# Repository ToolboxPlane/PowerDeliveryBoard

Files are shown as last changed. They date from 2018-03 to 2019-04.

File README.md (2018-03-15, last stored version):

View this project on [CADLAB.io](https://cadlab.io/node/755). 

# PowerDeliveryBoard

This board provides and monitors a 5V and 3.3V rail and monitors battery voltage and current.

Top Side|Bottom Side
:-------------------------:|:-------------------------:
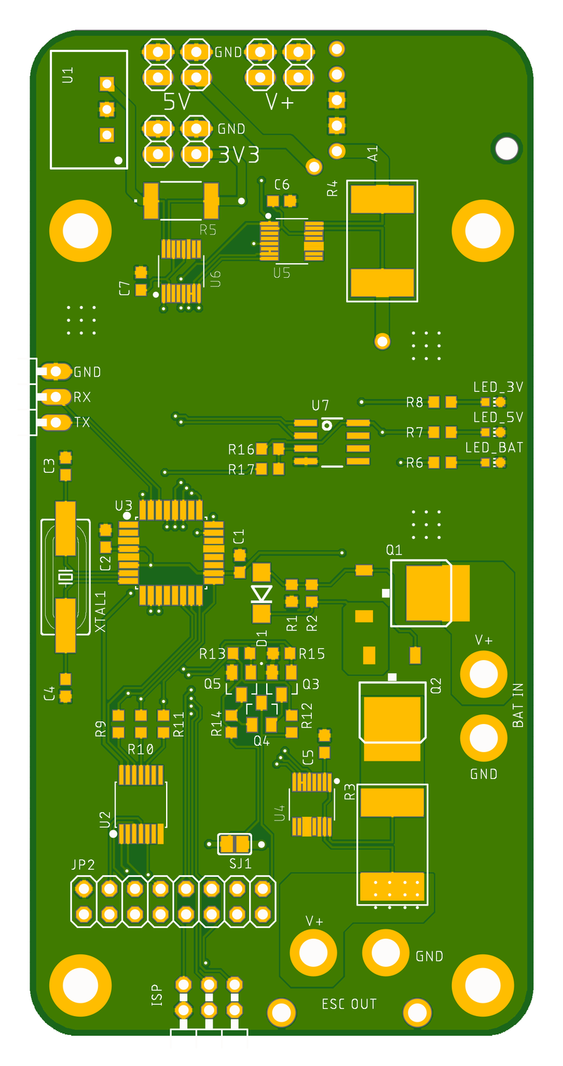
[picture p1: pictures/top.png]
Top Side
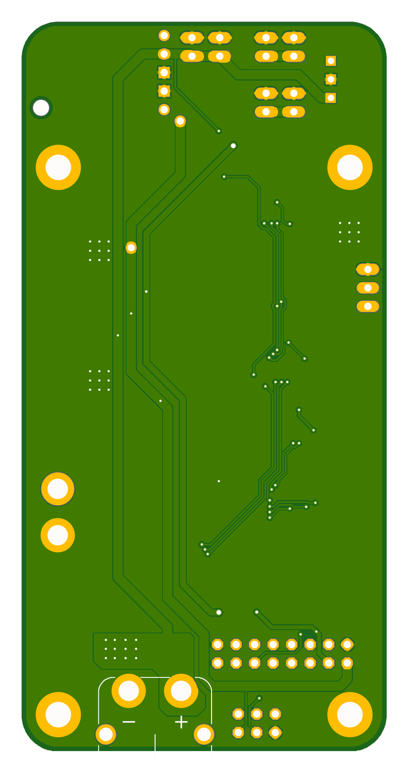
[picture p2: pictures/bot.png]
Bottom Side
|

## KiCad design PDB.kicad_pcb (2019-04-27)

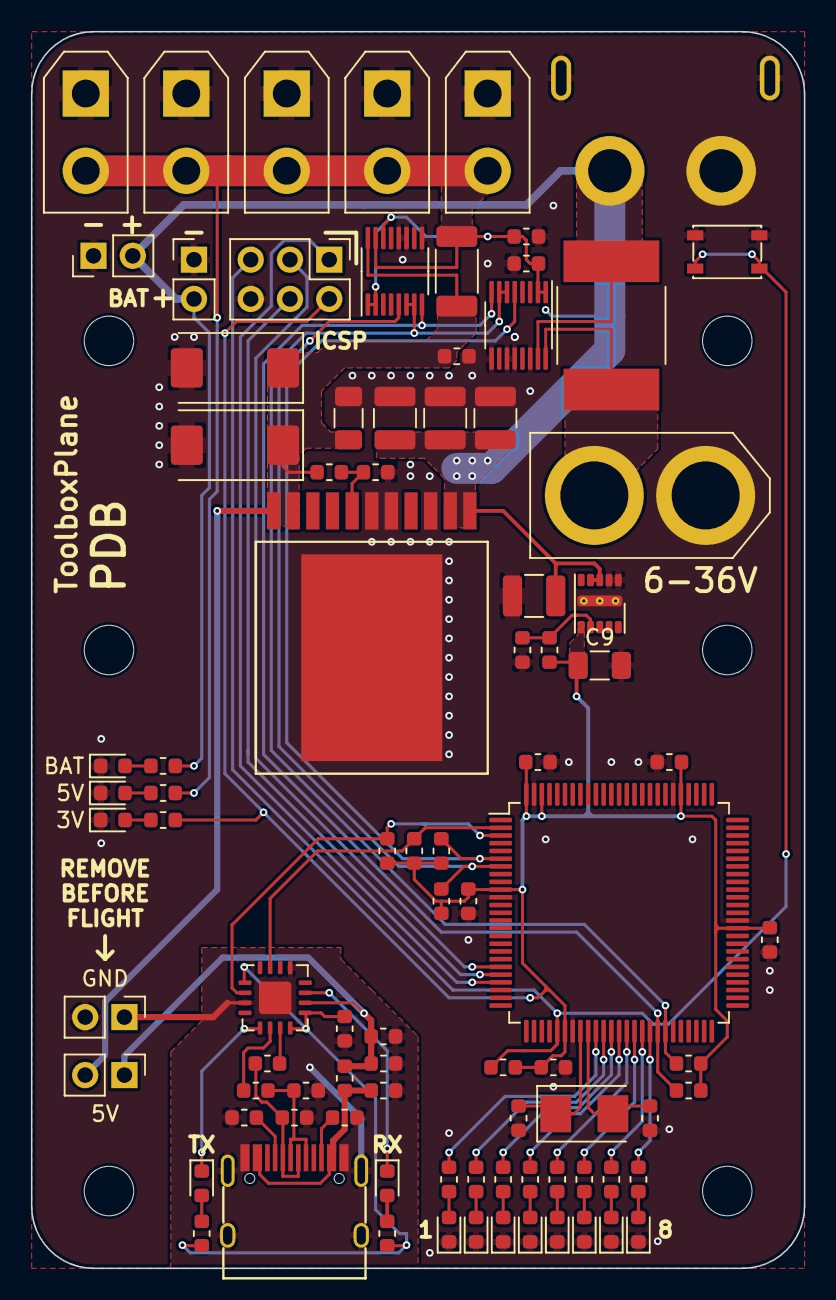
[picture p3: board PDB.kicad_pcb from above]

Board: 2 copper layers, 50.0 x 80.0 mm, 95 parts (0 on the bottom side), 53 nets.

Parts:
C1, C2: 8pF; C_0603_1608Metric
C3, C4, C5, C6, C7, C14, C16: 100nF; C_0603_1608Metric
C8: 10µF; C_1210_3225Metric
C9: 22µF; C_1206_3216Metric
C10, C24: 100n; C_0603_1608Metric
C11, C12: 47p; C_0603_1608Metric
C13: 10nF; C_0603_1608Metric
C15: 4.7µF; C_0603_1608Metric
C17, C18, C19: 10µ; C_1210_3225Metric
C20: 47n; C_0603_1608Metric
C21, C22: 330µ; CP_EIA-7343-31_Kemet-D
C23: 47µ; C_1206_3216Metric
D1: blue; LED_0603_1608Metric
D2: green; LED_0603_1608Metric
D3: orange; LED_0603_1608Metric
D4, D5, D6, D7, D8, D9, D10, D11: LED_0603_1608Metric
D12, D13: LED_Small; LED_0603_1608Metric
FB1: 600 Ohms @ 100MHz; C_0603_1608Metric
H1, H2, H3, H4, H5, H6: MountingHole; MountingHole_3.2mm_M3
J1, J2, J3, J4, J5: Conn_01x02; AMASS_XT30UPB-F_1x02_P5.0mm_Vertical
J6, J7: Conn_01x02; PinHeader_1x02_P2.54mm_Vertical
J8: Conn_01x02; XT60PB-M
J9: Conn_02x03_Odd_Even; PinHeader_2x03_P2.54mm_Vertical
J10: Conn_01x02_MountingPin; XT60PW-F
J11: USB_C_Receptacle_USB2.0; USB_C_Receptacle_GT-USB-7010
JP1, JP2: Jumper; PinHeader_1x02_P2.54mm_Vertical
R1, R29: 2.8k; R_0603_1608Metric
R2, R3, R14, R15, R16, R17, R18: 10k; R_0603_1608Metric
R4: 470; R_0603_1608Metric
R5, R26, R27: 270; R_0603_1608Metric
R6, R7, R8, R9, R10, R11, R12, R13: 100; R_0603_1608Metric
R19: 11.5k; R_0603_1608Metric
R20: 4.99k; R_0603_1608Metric
R21: 2m; R_3920
R22, R23: 5.1k; R_0603_1608Metric
R24, R25: 27; R_0603_1608Metric
R28: 14.7k; R_0603_1608Metric
R30: 8m; R_2010_5025Metric
SW1: SW_Push; SW_SPST_PTS810
U1: ATmega2560-16AU; TQFP-100_14x14mm_P0.5mm
U2: LMZM23600; Texas_SIL0010A_MicroSiP-10-1EP_3.8x3mm_P0.6mm_EP0.7x2.9mm_T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
U3, U6: LTC2946; MSOP-16_3x4mm_P0.5mm
U4: FT230XQ; QFN-16-1EP_4x4mm_P0.65mm_EP2.1x2.1mm
U5: LMZ13608
Y1: 16MHz; Crystal_SMD_5032-2Pin_5.0x3.2mm

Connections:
+3V3: C3.2, C4.2, C5.2, C6.2, C7.2, C9.1, J9.2, R2.1, R3.1, R5.1, R14.1, R15.1, R16.1, R17.1, R18.1, R19.1, U1.10, U1.31, U1.61, U1.80, U1.98, U1.100, U2.6
+5V: C10.1, C24.1, J1.2, J2.2, J3.2, J4.2, J5.2, R4.1, R30.1, U3.1, U3.2, U6.1, U6.2, U6.14, U6.15
+BATT: C8.1, C17.1, C18.1, C19.1, J6.2, J7.2, J10.2, R1.1, R21.1, U2.3, U2.4, U3.15, U5.1, U5.2
/5V/5VIN: C20.1, C21.1, C22.1, C23.1, JP1.2, R28.1, R30.2, U5.10, U5.11, U6.16
/ATMega/MISO: J9.1, U1.22
/ATMega/MOSI: J9.4, U1.21
/ATMega/SCK: J9.3, U1.20
/ATMega/~RESET~: J9.5, R14.2, SW1.2, U1.30
/BAT/VBATIN: J8.2, R21.2, U3.16
/FT230/5VOUT: C14.1, C15.1, FB1.1, JP1.1, U4.10
/RX: R2.2, U1.2, U4.15
/SCL: R16.2, U1.43, U3.8, U6.8
/SDA: R15.2, U1.44, U3.6, U3.7, U6.6, U6.7
/TX: R3.2, U1.3, U4.2
/~ALERT_+5V~: R18.2, U1.7, U6.5
/~ALERT_VBAT~: R17.2, U1.6, U3.5
GND: C1.2, C2.2, C3.1, C4.1, C5.1, C6.1, C7.1, C8.2, C9.2, C10.2, C17.2, C18.2, C19.2, C20.2, C21.2, C22.2, C23.2, C24.2, D1.1, D2.1, D3.1, D4.1, D5.1, D6.1, D7.1, D8.1, D9.1, D10.1, D11.1, J1.1, J2.1, J3.1, J4.1, J5.1, J6.1, J7.1, J8.1, J9.6, J10.1, J10.MP, JP2.2, R20.1, R29.2, SW1.1, U1.11, U1.32, U1.62, U1.81, U1.99, U2.1, U2.2, U2.11, U3.9, U3.11, U3.12, U3.14, U5.3, U5.5, U5.6, U5.PAD, U6.9, U6.11, U6.12
GNDS: C11.2, C12.2, C13.2, C14.2, C15.2, C16.2, J11.A1, J11.A12, J11.B1, J11.B12, J11.S1, JP2.1, R22.1, R23.1, U4.3, U4.13, U4.17
unnamed: C1.1, U1.34, Y1.2
unnamed: C2.1, U1.33, Y1.1
unnamed: C11.1, J11.A7, J11.B7, R24.2
unnamed: C12.1, J11.A6, J11.B6, R25.2
unnamed: C16.1, R26.1, R27.1, U4.1, U4.8, U4.9
unnamed: D1.2, R1.2
unnamed: D2.2, R4.2
unnamed: D3.2, R5.2
unnamed: D4.2, R6.2
unnamed: D5.2, R7.2
unnamed: D6.2, R8.2
unnamed: D7.2, R9.2
unnamed: D8.2, R10.2
unnamed: D9.2, R11.2
unnamed: D10.2, R12.2
unnamed: D11.2, R13.2
unnamed: D12.1, U4.11
unnamed: D12.2, R26.2
unnamed: D13.1, U4.5
unnamed: D13.2, R27.2
unnamed: J11.A5, R22.2
unnamed: J11.B5, R23.2
unnamed: R6.1, U1.35
unnamed: R7.1, U1.36
unnamed: R8.1, U1.37
unnamed: R9.1, U1.38
unnamed: R10.1, U1.39
unnamed: R11.1, U1.40
unnamed: R12.1, U1.41
unnamed: R13.1, U1.42
unnamed: R19.2, R20.2, U2.7
unnamed: R24.1, U4.7
unnamed: R25.1, U4.6
unnamed: R28.2, R29.1, U5.7
VBUS: C13.1, FB1.2, J11.A4, J11.A9, J11.B4, J11.B9

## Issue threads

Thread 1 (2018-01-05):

Platzierung der hohen Bauteile

niklas26, 2018-01-05:
Optionen:
-Längeres Board
-höhere Pinnleisten
-?

aul12, 2018-01-05:
Bin für längeres Board. Dann können in der überstehenden Fläche zusätzliche Schraublöcher angebracht werden und der komplette Stack einfach daran festgeschraubt werden und die Platinen müssen nicht nacheinander festgeschraubt werden

Closed 2018-01-25.

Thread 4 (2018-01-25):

Welchen Sinn hat L2 hinter dem Traco?

swappad, 2018-01-25:
Nicht lieber davor?

niklas26, 2018-01-30:
Ne das passt schon so, wird geglättet wenn das Signal raus kommt.
Siehe dazu auch das DB des Tracos

Closed 2018-03-12.

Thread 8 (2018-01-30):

Select appropriate shunt for 3v3, 5v

ottojo, 2018-01-30:

ottojo, 2018-01-30:
Done: 5V uses the same 2mOhm as VBAT,
3V3 uses "CRA2512-FZ-R040ELF" 40mOhm in 2512 package

This results in a resoultion of:

Voltage | Maximum Current | Resolution
-- | -- | --
VBAT (<= 16.8V) | 51,2A | 12.5mA
5V | 51,2A | 12.5mA
3V3 | 2,56A | 0,625mA

Closed 2018-02-01.

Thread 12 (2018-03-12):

fix atmega footprint

ottojo, 2018-03-12:
footprint does not match TQFP package

Closed 2018-03-12.

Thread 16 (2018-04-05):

Add Power Monitoring to new board

ottojo, 2018-04-05:
Well maybe we remember to connect the enable pin now, on the second try...
OE should be connected to 3V3

Closed 2018-08-22.

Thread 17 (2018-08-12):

Implement 5V regulation

ottojo, 2018-08-12:
U_BAT (12V-17V) to 5V, ~5A (?)

ottojo, 2018-08-12:
Suggestion: Texas Instruments LMZ12008TZ ([digikey](https://www.digikey.de/product-detail/de/texas-instruments/LMZ12008TZ-NOPB/LMZ12008TZ-NOPB-ND/2626433))

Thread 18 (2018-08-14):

USB to UART for communication with FlightComputer

ottojo, 2018-08-14:

ottojo, 2018-08-14:
FT230XQ

ottojo, 2018-08-22:
TODO: figure out if pull-up resistors are needed on rx/tx

ottojo, 2018-08-22:
todo: see above

ottojo, 2019-03-12:
https://github.com/ToolboxPlane/FT230Module

Closed 2019-03-12.

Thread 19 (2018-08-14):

Figure out naming (Delivery/Distribution)

ottojo, 2018-08-14:

ottojo, 2018-08-14:
"Electric power distribution is the final stage in the delivery of electric power"

aul12, 2018-08-14:
Delivery klingt gut

Closed 2018-08-14.

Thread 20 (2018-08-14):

Remove (or thoroughly think about) polarity protection

ottojo, 2018-08-14:
Q2 blew up on first launch.

ottojo, 2018-09-03:
Thoughts on this: Polarity protection by not fucking up soldering the XT60 will probably be enough.

Closed 2019-03-12.

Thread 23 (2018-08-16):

Outputs

ottojo, 2018-08-16:
Outputs needed:
XT60 for Motor
As many XT30 for 5V as reasonably fit on the board

aul12, 2018-08-17:
On the expansion port a 5V rail is required as well (HC-SR04)

ottojo, 2018-08-17:
Related: Find general purpose power connector for peripherals that only require power (FPV Cam, LEDs, ...)

ottojo, 2019-03-12:
I propose using USB C for FC @aul12

Closed 2019-04-13.

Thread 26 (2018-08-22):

Fix voltage levels

ottojo, 2018-08-22:
PDB atmega should be running at 3.3v, not 5v

Closed 2018-08-22.

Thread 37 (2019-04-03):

Short term TODO

ottojo, 2019-04-03:
- [x] Decide Power Connector for Pi (suggestion: XT30 -> weird cable to micro USB)
- [x] Add VBAT pins for peripherals
- [x] Verify (fix) XT(3|6)0 footprints
- [x] Power LEDs
- [x] LTC2946 Supply by something else than VIN
- [x] Label LEDs
- [ ] Eval LMZ21700SILR

aul12, 2019-04-03:
- [ ] 8 LEDs instead of 4
- [ ] Reset Button

Closed 2019-04-09.

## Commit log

2018-01-04 Connected Levelshifter
    [pdb.brd, pdb.sch]
2018-01-04 First parts placed
    [pdb.brd, pdb.sch]
2018-01-04 added temperature sensor
    [pdb.brd, pdb.sch]
2018-01-04 updated inductor for 3v regulator
    [pdb.brd, pdb.sch]
2018-01-04 added mounting holes
    [pdb.brd]
2018-01-08 AT30TS74 connected
    [pdb.brd, pdb.sch]
2018-01-09 Header connected, First Layout attempt
    [pdb.brd, pdb.sch]
2018-01-09 5v nearly completely connected
    [pdb.brd, pdb.sch]
2018-01-11 First Layout GND not connected because of wrong design rules
    [pdb.brd]
2018-01-12 fixed spi level shifting
    [pdb.brd, pdb.sch]
2018-01-15 First Version, nearly completed
    [pdb.brd, pdb.sch]
2018-01-22 added net classes
    [pdb.brd, pdb.sch]
2018-01-22 assigned net classes
    [pdb.brd, pdb.sch]
2018-01-22 fixed some signal trace widths
    [pdb.brd, pdb.sch]
2018-01-23 ISP, SPI, I2C Bus layout
    [pdb.brd, pdb.sch]
2018-01-23 added shunts
    [pdb.brd, pdb.sch]
2018-01-24 fixed xt60, updated libs
    [pdb.brd, pdb.sch]
2018-01-24 more wip
    [pdb.brd]
2018-01-26 changed R6
    [pdb.brd, pdb.sch]
2018-01-30 fixed shunt resistor libraries
    [pdb.brd, pdb.sch]
2018-01-30 fixed #5
    [pdb.brd]
2018-01-30 fixed vbat routing for better ground path
    [pdb.brd]
2018-01-30 fixed shunt resistor value
    [pdb.brd, pdb.sch]
2018-01-30 design rules
    [pdb.brd]
2018-02-01 fixed min drill
2018-02-09 various improvements/fixes
    added power output pins
    fixed design rules
    moved ESC out to bottom
    fixed packages
    removed unnecessary filtering for atmega
    etc
    (may be more but that was last week i don't remember anymore)
    [pdb.brd, pdb.sch]
2018-02-09 fixed #10
    removed expansion port connections
    rotated expansion port
    connected expansion port
    added 3V3 jumper
    [pdb.brd, pdb.sch]
2018-02-09 changed atmega routing
    [pdb.brd]
2018-02-09 fixed via stop limit
    [pdb.brd]
2018-02-14 various changes
    removed netclasses, might add them later again, creates issues with sense lines
    fixed output pin
    version bump
    fixed some vias/drills
    [pdb.brd, pdb.sch]
2018-02-14 gnd routing
    netclasses
    [pdb.brd, pdb.sch]
2018-02-23 sachen gemacht dass fusion glücklich ist
    [pdb.brd, pdb.sch]
2018-02-23 layout stuff
    [pdb.brd, pdb.sch]
2018-02-24 multiple changes
    removed inductor,
    fixed layout + schematic
    [pdb.brd, pdb.sch]
2018-03-11 various changes
    moved smd components on metric grid
    silkscreen, reduced fuckup in part sizes
    added output
    [pdb.brd, pdb.sch]
2018-03-12 fixed 3d models
    [pdb.brd, pdb.sch]
2018-03-12 added reset, closed #11
    [pdb.brd, pdb.sch]
2018-03-12 fixed layout, silkscreen, resistor values
    [pdb.brd, pdb.sch]
2018-03-12 changed LTC2946 for easier soldering
    [pdb.brd, pdb.sch]
2018-03-12 fixed atmega
    closes #12
    [pdb.brd, pdb.sch]
2018-03-12 fixed naming, silkscreen
    [pdb.brd, pdb.sch]
2018-03-12 silkscreen fixes
    [pdb.brd, pdb.sch]
2018-03-12 added temperature alert
    [pdb.brd, pdb.sch]
2018-03-12 added serial port
    [pdb.brd, pdb.sch]
2018-03-12 fixed silkscreen: jp8
    [pdb.brd]
2018-03-12 fixed gnd routing
    [pdb.brd, pdb.sch]
2018-03-12 fixed levelshifter footprint
    [pdb.brd, pdb.sch]
2018-03-12 R value levelshifter
    [pdb.brd, pdb.sch]
2018-03-12 ti lib update
    [pdb.brd, pdb.sch]
2018-03-13 improved high current traces
    [pdb.brd]
2018-03-13 removed unnecessary gnd traces
    [pdb.brd]
2018-03-14 fixed typo
    [pdb.brd, pdb.sch]
2018-08-14 remove old schematic
    [pdb.sch]
2018-08-14 adds new empty schematic
    [pdb.sch]
2018-08-14 adds frame
    [pdb.sch]
2018-08-14 adds LMZ13608 and resistors to set output voltage
    [pdb.sch]
2018-08-16 Cin, formatting
    not only the library file this time
    [pdb.sch]
2018-08-22 added ATmega
    + crystal, ISP
    [pdb.sch]
2018-08-22 adds FT230X
    [pdb.sch]
2018-08-22 fix atmega supply voltage
    fixes #26
    [pdb.sch]
2018-08-22 adds power monitoring
    [pdb.sch]
2018-08-22 adds 4 programmable LEDs on PL0-PL3
    [pdb.sch]
2018-08-30 adds expansion port
    [pdb.sch]
2018-09-02 3.3v regulation
    [pdb.sch]
2018-09-03 adds missing schottky diode for 3.3v reg
    fixes #30
    [pdb.sch]
2018-09-04 adds XT60
    [pdb.sch]
2018-09-08 adds FlightComputer USB connector
    [pdb.sch]
2019-02-22 assign vbat shunt footprint
    [BAT.sch]
2019-02-22 LMZ13608 input caps
    [5V.sch]
2019-02-22 fix missing footprint
    [5V.sch]
2019-02-22 LMZ13608 output caps
    [5V.sch]
2019-02-22 5V shunt
    [5V.sch]
2019-02-23 fix footprints
    [5V.sch, ATMega.sch, FT230.sch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]
2019-02-23 fix serial connection ftdi-atmega
    [PDB.sch]
2019-02-27 update footprints
    [5V.sch, FT230.sch]
2019-03-03 move FT230 to https://github.com/ToolboxPlane/FT230Module
    [FT230.sch, PDB.sch]
2019-03-12 smaller shunt on 5v rail
    [5V.sch]
2019-03-12 add rx/tx labels
    [PDB.sch]
2019-03-12 annotate parts
    [3V3.sch, 5V.sch, ATMega.sch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]
2019-03-12 update USB footprint
2019-03-13 update XT60
    [BAT.sch, PDB.sch]
2019-03-13 update USB C footprint
2019-03-13 add XT30 5V Out
    [PDB.sch]
2019-03-13 3v3 regulator 3d model
2019-03-13 USB C Power Port
    [PDB.sch]
2019-03-13 layout wip
    [PDB.kicad_pcb]
2019-04-03 wip und so
    [3V3.sch, 5V.sch, ATMega.sch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]
2019-04-03 add reset switch
    [ATMega.sch, PDB.kicad_pcb, PDB.sch]
2019-04-03 LMZM23600 from kicad libs
    [3V3.sch, 5V.sch, ATMega.sch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]
2019-04-04 remove isolation from FT230
    [PDB.kicad_pcb, PDB.sch]
2019-04-04 more LEDs
    [3V3.sch, 5V.sch, ATMega.sch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]
2019-04-05 more layout
    [PDB.kicad_pcb]
2019-04-05 even more layout
    [5V.sch, BAT.sch, PDB.kicad_pcb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]
2019-04-05 layout fixes, reannotate
    [3V3.sch, 5V.sch, ATMega.sch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]
2019-04-05 silkscreen stuff
2019-04-05 the ACTUAL silkscreen stuff, including the actual changes this time
    [PDB.kicad_pcb]
2019-04-05 use official XT30 footprint
    [PDB.kicad_pcb, PDB.sch]
2019-04-05 rounded corners
    [PDB.kicad_pcb]
2019-04-05 add missing trace near USB
    [PDB.kicad_pcb]
2019-04-07 mounting dimensions
    [PDB.kicad_pcb]
2019-04-07 oshw logo
    [PDB.kicad_pcb]
2019-04-07 rebuild zones
    [PDB.kicad_pcb]
2019-04-07 fix 3.3v regulator output cap
    [3V3.sch, PDB.kicad_pcb]
2019-04-07 fix thermals for 5V out
    [PDB.kicad_pcb]
2019-04-07 layout fixes
    [PDB.kicad_pcb]
2019-04-07 add large toolbox logo on bottom side
    [PDB.kicad_pcb]
2019-04-27 fix LEDs
    [PDB.kicad_pcb, PDB.sch]
2019-04-27 fix debug LED resistors
    [ATMega.sch, PDB.kicad_pcb]
